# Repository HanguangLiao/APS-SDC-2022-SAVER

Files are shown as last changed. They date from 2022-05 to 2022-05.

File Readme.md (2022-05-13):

## About this Repository
The repo contains the hardware and software of the Small Antenna for Vital Emergency Response (SAVER) for APS SDC 2022. It consists of pluggable blocks for miniaturized antennas, an antenna testbench, a wristband which monitors vital signs and a mobile phone app which collects, analyzes, and plots the vital signs from the wristband.

## Folder Structure
* Antenna Testbench
    * Antenna Hardware
        - STL and STEP files of the pluggable antenna blocks
    * GUI
        - GUI of the antenna testbench run on a Raspberry Pi 4 which is also connected to PocketVNA.
* Mobile Phone App
    - MIT App Inventor Project File and the Released APK file
* Wristband
    * Hardware
        - Gerber Files, schematics, soldering guide, and bill of materials of the Wristband PCB
        * Wristband support printing
            - STL and STEP files of the wristband case
    * Software
        - PlatformIO project folder of the wristband firmware

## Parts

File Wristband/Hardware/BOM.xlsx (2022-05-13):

Name | Description | Designator | Value | Quantity
Cap | Capacitor | C1, C2 | 18pF | 2 | 31
Cap | Capacitor | C3, C9, C18, C29, C33 | 1uF | 5
Cap | Capacitor | C4, C7, C8, C10, C13, C14, C15, C19, C21, C23, C24, C25, C28, C32 | 0.1uF | 14
Cap | Capacitor | C5 | 10nF | 1
Cap | Capacitor | C6 | 3.3nF | 1
Cap | Capacitor | C11, C26, C27 | 10uF | 3
Cap | Capacitor | C16, C17 | 270pF | 2
Cap | Capacitor | C22 | 2.2nF | 1
Cap | Capacitor | C30 | 10pF | 1
Cap | Capacitor | C31 | 7pF | 1
Diode 10TQ035 | Schottky Rectifier | D1, D2 |  | 2
Antenna | Generic Antenna | E1 |  | 1
USB |  | J |  | 1
Inductor | Inductor | L1 | 1nH | 1
TS9011DCX_RFG | 250mA 1.8V Low Quiescent Current CMOS LDO | LDO1.8 |  | 1
ESP32-D0WDQ6 | IC RF TxRx + MCU Bluetooth, WiFi 802.11b/g/n, Bluetooth 4.2 2.4GHz 48-VFQFN Exposed Pad | MPU |  | 1
Header 2H | Header, 2-Pin, Right Angle | P1 |  | 1
Res3 | Resistor | R1, R10 | 20K | 2 | 19
Res3 | Resistor | R2, R11, R12 | 4.7K | 3
Res3 | Resistor | R3, R4, R7, R8 | 4.7k | 4
Res3 | Resistor | R9, R20, R21 | 0 | 3
Res3 | Resistor | R13 | 500 | 1
Res3 | Resistor | R14, R15, R16, R17, R18, R19 | 10k | 6
SW-SPST | Single-Pole, Single-Throw Switch | S1, S2 |  | 2
W25Q32JVSSIQ | FLASH - NOR Memory IC 32Mb _4M x 8_ SPI - Quad I/O 133MHz 8-SOIC | U |  | 1
MPU-6050 | Accelerometer, Gyroscope, 6 Axis Sensor IÂ²C Output | U2 |  | 1
MAX30102EFD+ | Oximeter/Heart Rate Sensor IÂ²C Output | U3 |  | 1
AMS1117-3.3 | Sot223/Pkg 1-Amp 3.3-Volt Low Drop Out Voltage Regulatator | U5 |  | 1
CH340E | USB to serial chip CH340 | U10 |  | 1
ABM8-40.000MHZ-10-1-U-T | 40MHz Â±10ppm Crystal 10pF 35 Ohms 4-SMD, No Lead | Y-40MHz |  | 1

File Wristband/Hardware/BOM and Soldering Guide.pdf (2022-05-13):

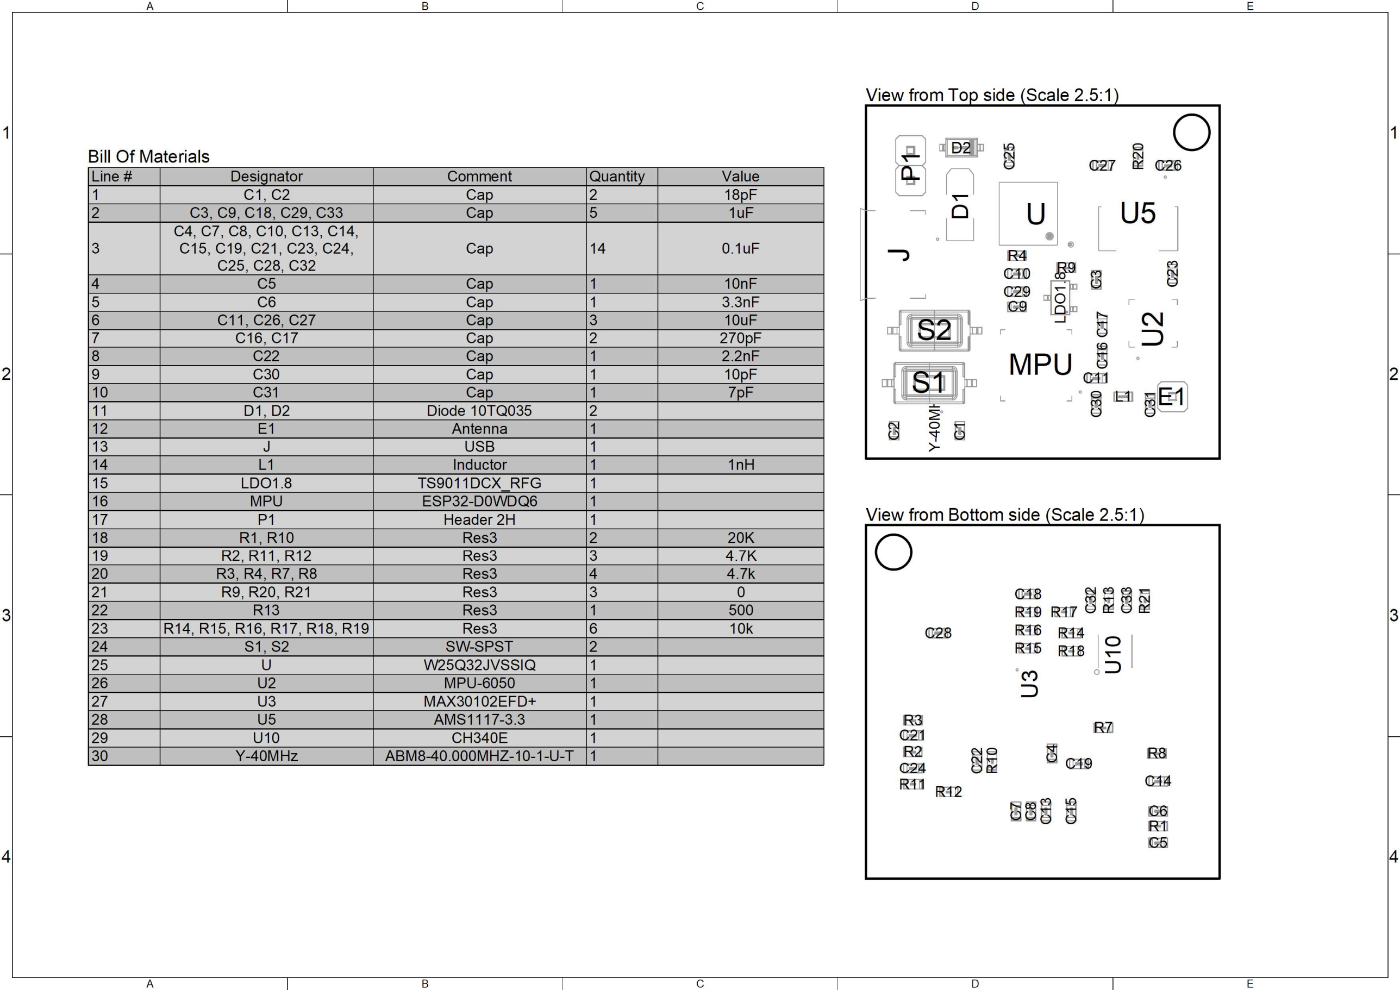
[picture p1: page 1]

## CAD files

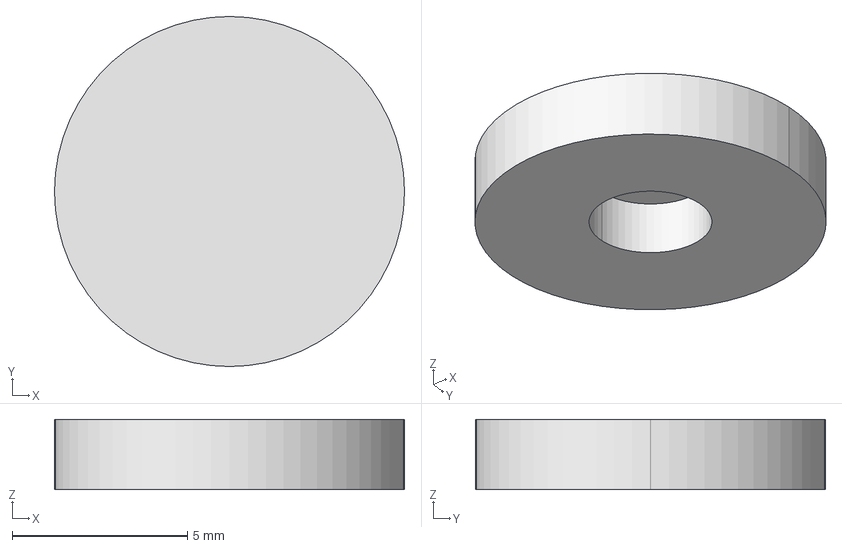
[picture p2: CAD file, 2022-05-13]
Antenna Testbench/Antenna Hardware/Antenna Models/top hat.step
10.0 x 10.0 x 2.00 mm

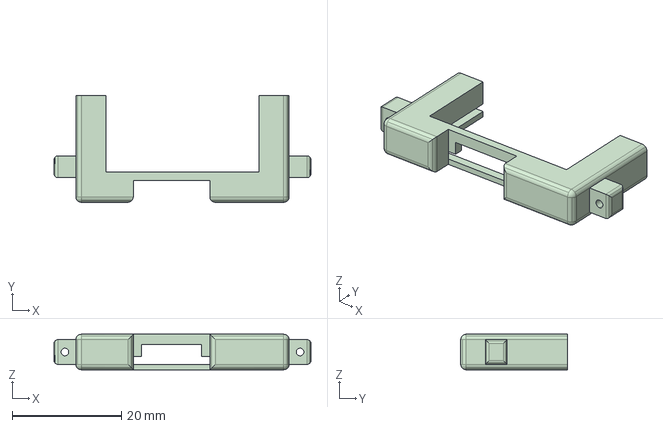
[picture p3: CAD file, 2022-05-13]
Wristband/Hardware/Wristband support printing/2nd_half.step
47.0 x 19.5 x 6.50 mm

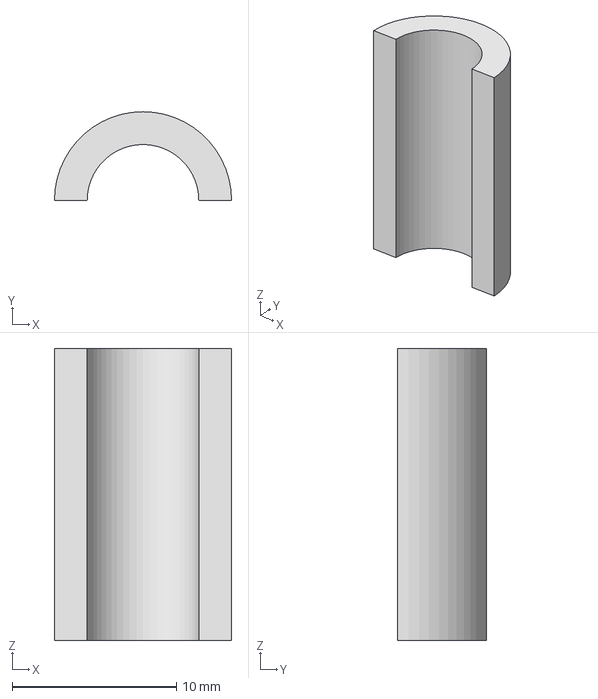
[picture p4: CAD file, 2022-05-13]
Antenna Testbench/Antenna Hardware/Antenna Models/L3.step
10.8 x 5.40 x 17.8 mm

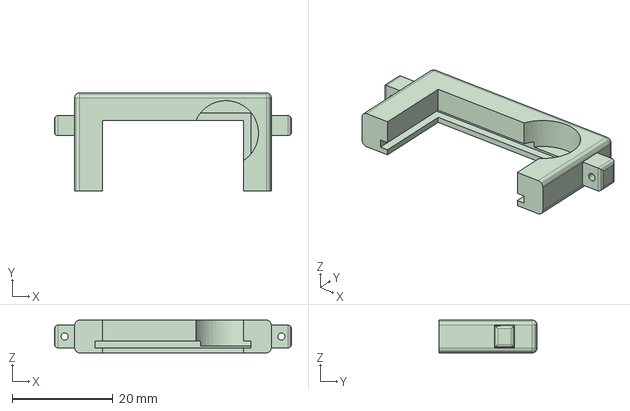
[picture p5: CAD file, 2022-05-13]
Wristband/Hardware/Wristband support printing/1st_half.step
47.0 x 19.5 x 6.50 mm

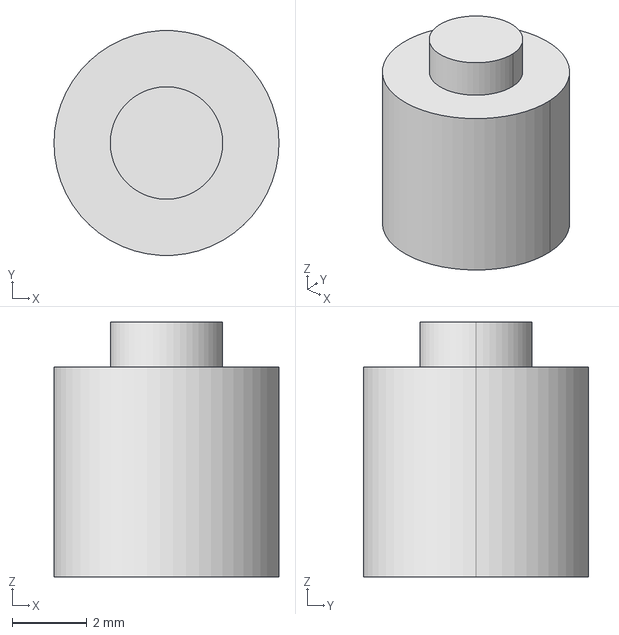
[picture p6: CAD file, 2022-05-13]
Antenna Testbench/Antenna Hardware/Antenna Models/Base.step
6.00 x 5.99 x 6.80 mm

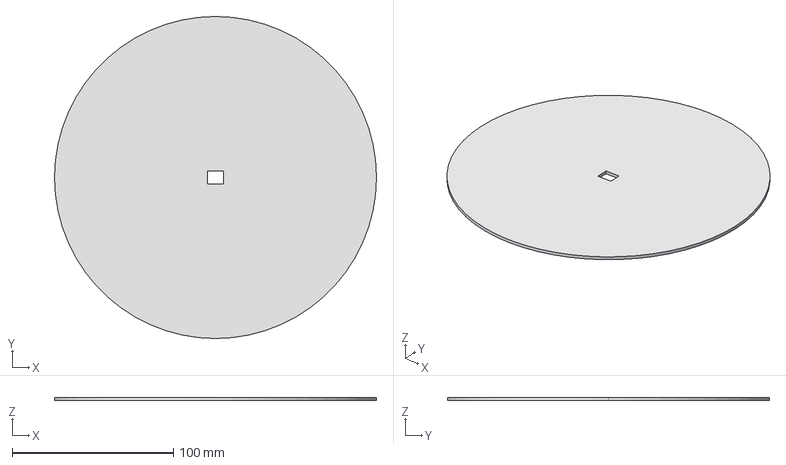
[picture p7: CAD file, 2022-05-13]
Antenna Testbench/Antenna Hardware/Antenna Models/GND_plane.step
200.0 x 200.0 x 2.00 mm

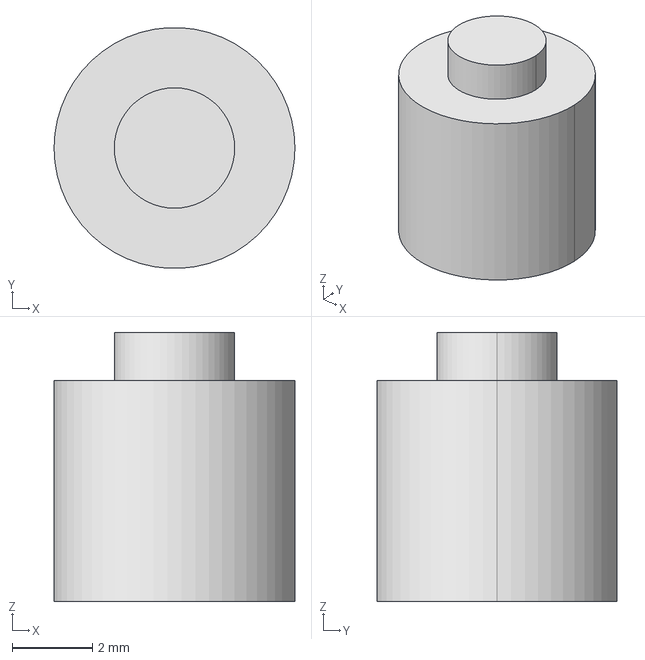
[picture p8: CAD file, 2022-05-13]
Antenna Testbench/Antenna Hardware/Antenna Models/Middle.step
6.00 x 5.99 x 6.70 mm

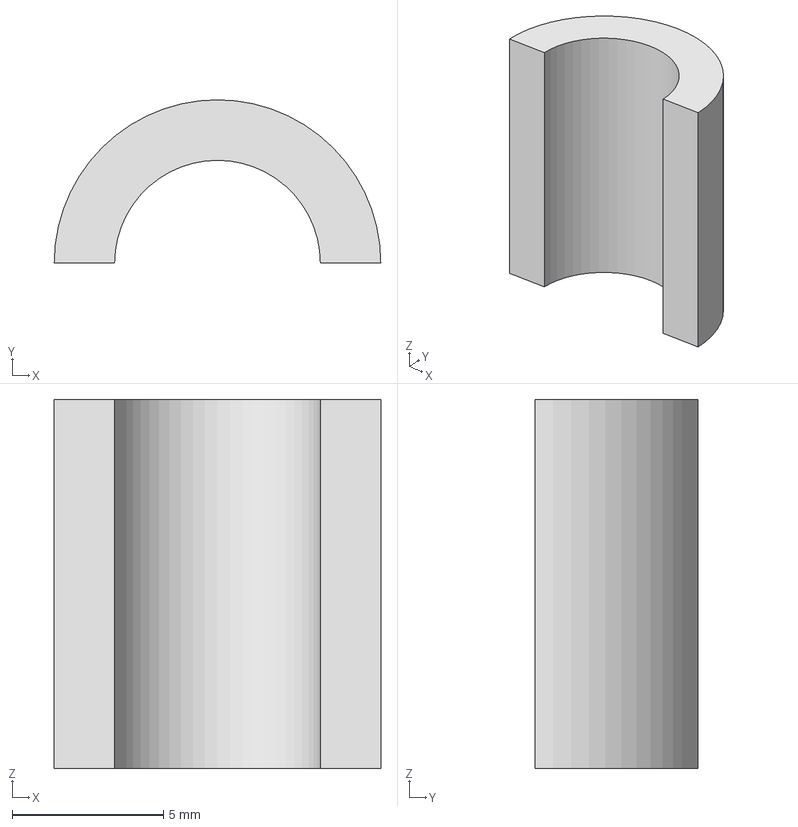
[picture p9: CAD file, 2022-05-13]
Antenna Testbench/Antenna Hardware/Antenna Models/L2.step
10.8 x 5.40 x 12.2 mm

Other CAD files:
Antenna Testbench/Antenna Hardware/Meandered linse cutting.dxf
Antenna Testbench/Antenna Hardware/Antenna Models/Base.STL
Antenna Testbench/Antenna Hardware/Antenna Models/GND_plane.STL
Antenna Testbench/Antenna Hardware/Antenna Models/L2.STL
Antenna Testbench/Antenna Hardware/Antenna Models/L3.STL
Antenna Testbench/Antenna Hardware/Antenna Models/Middle.STL
Antenna Testbench/Antenna Hardware/Antenna Models/top hat.STL
Wristband/Hardware/Wristband support printing/1st_half.STL
Wristband/Hardware/Wristband support printing/2nd_half.STL

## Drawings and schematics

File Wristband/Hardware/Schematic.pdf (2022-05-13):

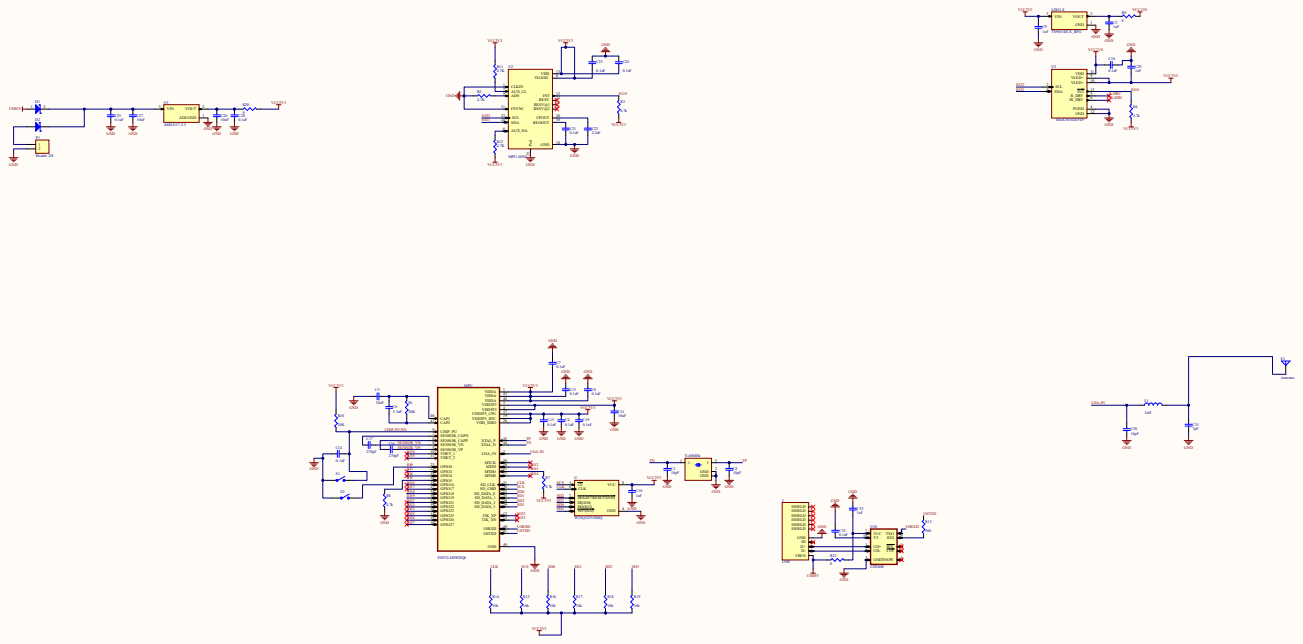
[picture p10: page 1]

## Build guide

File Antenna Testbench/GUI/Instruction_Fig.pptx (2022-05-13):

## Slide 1

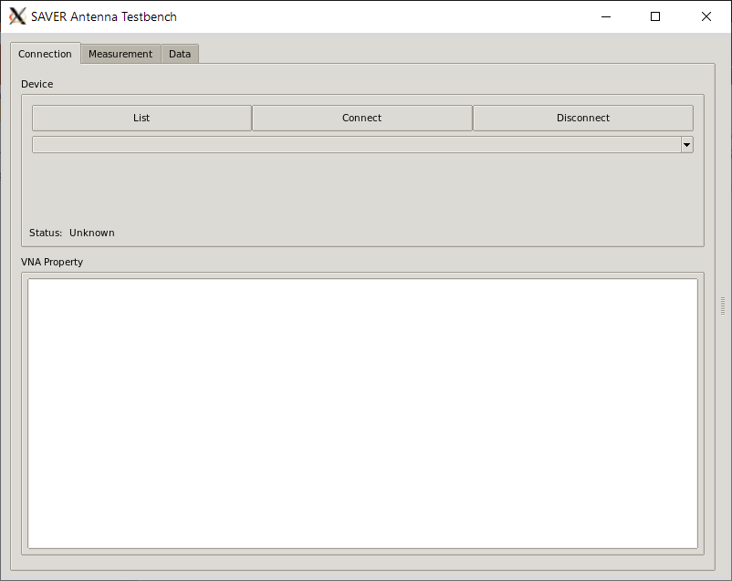
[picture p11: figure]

Step8.1

Step8.2

Step8.3

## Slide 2

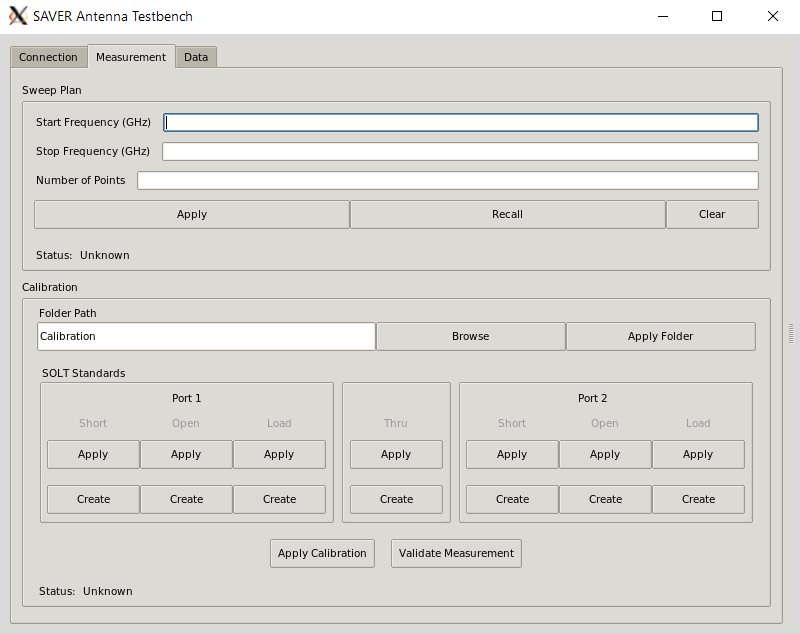
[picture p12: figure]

Step9.1

Step9.2

Step10

Step11

Step12

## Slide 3

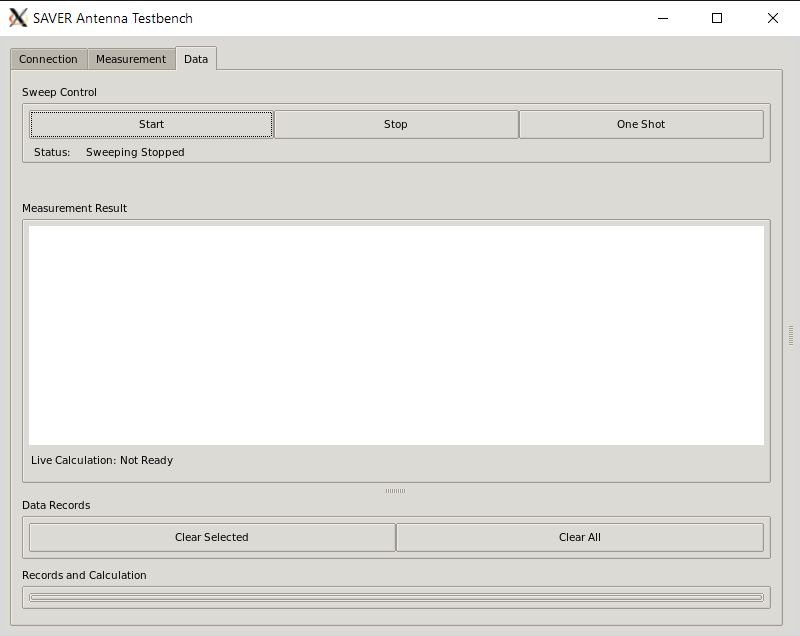
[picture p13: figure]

Step13

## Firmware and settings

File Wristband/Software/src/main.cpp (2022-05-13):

#include <Arduino.h>
#include <BLEDevice.h>
#include <BLEServer.h>
#include <BLEUtils.h>
#include <BLE2902.h>
#include <Wire.h>
#include <math.h>
#include <MAX30105.h>
#include <spo2_algorithm.h>
// Mutex and Semaphore Definitions
SemaphoreHandle_t mutex_iic;
//--------------UART--Server--Task--Begin----------------------------------
QueueHandle_t queue_serial;
const int queue_serial_buffer_size = 128;
static void task_serial_server(void * param)
{
  char receive_buffer[queue_serial_buffer_size];

  Serial.begin(115200);
  while(1)
  {
    // If receives queued request to print on serial
    if(xQueueReceive(queue_serial,receive_buffer,128) == pdTRUE)
    {
      Serial.printf("%s\n", receive_buffer);
    }
    vTaskDelay(100 / portTICK_PERIOD_MS);
  }
}
//--------------UART--Server--Task--End-----------------------------------

//--------------BLE--Server--Task--Begin-----------------------------------
QueueHandle_t queue_ble_temperature,
 queue_ble_accel, 
 queue_ble_heartbeat, 
 queue_ble_spo2;
#define SERVICE_UUID "12a59900-17cc-11ec-9621-0242ac130002"
#define CHARACTERISTIC_UUID_SPO2 "12a5a148-17cc-11ec-9621-0242ac130002"
#define CHARACTERISTIC_UUID_TEMP "a93769a2-ace1-11ec-b909-0242ac120002"
#define CHARACTERISTIC_UUID_TXHB "d084d792-ace1-11ec-b909-0242ac120002"
#define CHARACTERISTIC_UUID_TXAcce "e6097a32-ace1-11ec-b909-0242ac120002"
class BLEServerCallback : public BLEServerCallbacks
{
  public :
    int is_device_connected = 0;
    int is_device_connected_last_time = 0;
    void onConnect(BLEServer *pServer)
      {
          is_device_connected = 1;
      };

      void onDisconnect(BLEServer *pServer)
      {
          is_device_connected = 0;
      }
};
static void task_ble_server(void * param)
{
  char serial_buffer[queue_serial_buffer_size];
  sprintf(serial_buffer,"BLE: Server Created");
  xQueueSend(queue_serial, serial_buffer, 128);
  BLEServerCallback ble_server_callback;
  BLEDevice::init("ESP32_BLE");
  // setup a BLE service
  BLEServer * ble_server = BLEDevice::createServer();
  ble_server->setCallbacks(&ble_server_callback);
  BLEService * ble_service = ble_server->createService(SERVICE_UUID);

  // setup BLE characteristics
  BLECharacteristic * ble_charcteristic_spo2 = ble_service->createCharacteristic(CHARACTERISTIC_UUID_SPO2, BLECharacteristic::PROPERTY_WRITE | BLECharacteristic::PROPERTY_READ);
  BLECharacteristic * ble_charcteristic_temp = ble_service->createCharacteristic(CHARACTERISTIC_UUID_TEMP, BLECharacteristic::PROPERTY_WRITE | BLECharacteristic::PROPERTY_READ);
  BLECharacteristic * ble_charcteristic_heartbeat = ble_service->createCharacteristic(CHARACTERISTIC_UUID_TXHB, BLECharacteristic::PROPERTY_WRITE | BLECharacteristic::PROPERTY_READ);
  BLECharacteristic * ble_charcteristic_accel = ble_service->createCharacteristic(CHARACTERISTIC_UUID_TXAcce, BLECharacteristic::PROPERTY_WRITE | BLECharacteristic::PROPERTY_READ);

  // Run BLE Service
  ble_service->start();              
  ble_server->getAdvertising()->start();
  sprintf(serial_buffer,"BLE: Waiting for Connection");
  xQueueSend(queue_serial, serial_buffer, 128);
  while(1)
  {
    if(!ble_server_callback.is_device_connected && ble_server_callback.is_device_connected_last_time)
    {
      // If device is disconnecting
      ble_server->startAdvertising();
      sprintf(serial_buffer,"BLE: Disconnected and Restart Broadcasting");
      xQueueSend(queue_serial, serial_buffer, 128);
      ble_server_callback.is_device_connected_last_time = ble_server_callback.is_device_connected;
    }
    else if (ble_server_callback.is_device_connected && !ble_server_callback.is_device_connected_last_time)
    {
      // If device is connected for the first time
      ble_server_callback.is_device_connected_last_time = 1;
      sprintf(serial_buffer,"BLE: Connected");
      xQueueSend(queue_serial, serial_buffer, 128);
    }

    if(ble_server_callback.is_device_connected)
    {
      float read_buffer;
      if(xQueueReceive(queue_ble_accel, &read_buffer, 0) == pdTRUE)
        ble_charcteristic_accel->setValue(read_buffer);

      if(xQueueReceive(queue_ble_spo2, &read_buffer, 0) == pdTRUE)
        ble_charcteristic_spo2->setValue(read_buffer);

      if(xQueueReceive(queue_ble_temperature, &read_buffer, 0) == pdTRUE)
        ble_charcteristic_temp->setValue(read_buffer);

      if(xQueueReceive(queue_ble_heartbeat, &read_buffer, 0) == pdTRUE)
        ble_charcteristic_heartbeat->setValue(read_buffer);
    }
    vTaskDelay(10 / portTICK_PERIOD_MS);
  }
}
//--------------BLE--Server--Task--End-------------------------------------

//--------------MAX30102-Sensor-Read-Task--Begin--------------------------------
QueueHandle_t queue_max30102_ir, queue_max30102_red;
static void task_max30102_read(void * param)
{
  MAX30105 max30105_sensor;
  
  char serial_buffer[queue_serial_buffer_size];
  
  float temperature = 0.0f;
  int temperature_wait_tick = 0;
  
  // Check if device is connected
  while(xSemaphoreTake(mutex_iic, 100) != pdTRUE);
  if(!max30105_sensor.begin(Wire, I2C_SPEED_FAST))
  {
    sprintf(serial_buffer, "MAX30105: Sensor was not found. Please check wiring/power");
    xQueueSend(queue_serial, serial_buffer, 0);
    // Quit this task if device is not found
    xSemaphoreGive(mutex_iic);
    vTaskDelete(NULL);
  }
  xSemaphoreGive(mutex_iic);

  // Initiate device
  int sampleRate = 200; //Options: 50, 100, 200, 400, 800, 1000, 1600, 3200, Sampling Rate is also limited by LED Pulse Width （Refer to Table 11)
  byte ledBrightness = 60; //Options: 0=Off to 255=50mA
  byte sampleAverage = 4; //Options: 1, 2, 4, 8, 16, 32
  byte ledMode = 2; //Options: 1 = Red only, 2 = Red + IR, 3 = Red + IR + Green
  int pulseWidth = 411; //Options: 69, 118, 215, 411
  int adcRange = 4096; //Options: 2048, 4096, 8192, 16384
  while(xSemaphoreTake(mutex_iic, 100) != pdTRUE);
  max30105_sensor.setup(ledBrightness, sampleAverage, ledMode, sampleRate, pulseWidth, adcRange); //Configure sensor with these settings
  xSemaphoreGive(mutex_iic);

  while(1)
  {
    // Read Temperature at a speed 101 times slower than red and ir sensor
    temperature_wait_tick += 1;
    if(temperature_wait_tick > 101)
    {
      temperature_wait_tick = 0;
      while(xSemaphoreTake(mutex_iic, 0) != pdTRUE);
      temperature = max30105_sensor.readTemperature();
      //Reset SPO2 Measurement
      max30105_sensor.clearFIFO();
      xSemaphoreGive(mutex_iic);
      xQueueSend(queue_ble_temperature, &temperature, 0);
      sprintf(serial_buffer, "MAX30102: Temperature = %.2f", temperature);
      xQueueSend(queue_serial, serial_buffer, 0);
    }

    // Read IR Value
    while(xSemaphoreTake(mutex_iic, 0) != pdTRUE) vTaskDelay(1);
    uint32_t IR = max30105_sensor.getIR();
    xSemaphoreGive(mutex_iic);
    while(IR == 0)
    {
      while(xSemaphoreTake(mutex_iic, 0) != pdTRUE) vTaskDelay(1);
      IR = max30105_sensor.getIR();
      xSemaphoreGive(mutex_iic);
    }
    xQueueSend(queue_max30102_ir, &IR, 0);

    // Read Red Value
    while(xSemaphoreTake(mutex_iic, 0) != pdTRUE) vTaskDelay(1);
    uint32_t Red =  max30105_sensor.getRed();
    xSemaphoreGive(mutex_iic);
    while(Red == 0)
    {
      while(xSemaphoreTake(mutex_iic, 0) != pdTRUE) vTaskDelay(1);
      Red =  max30105_sensor.getRed();
      xSemaphoreGive(mutex_iic);
    }
    xQueueSend(queue_max30102_red, &Red, 0);

    // Sampling Rate: 25Hz (4 averaging of 200Hz / 2 Channels)
  }
}
//--------------MAX30102-Sensor-Read-Task--End--------------------------------

//--------------Heartbeat-SpO2-Algorithm-Begin--------------------------------
static void task_heartbeat_spo2_algorithm(void * param)
{
  // The bufferLength must be matched with BUFFER_SIZE in spo2_algorithm.h
  const int bufferLength = 100; //Sample Rate is 25Hz, Buffer takes 1000ms / 25 * 100 = 4 seconds to be filled
  uint32_t * irBuffer = (uint32_t * )pvPortMalloc(bufferLength * sizeof(uint32_t)); //infrared LED sensor data
  uint32_t * redBuffer = (uint32_t * )pvPortMalloc(bufferLength * sizeof(uint32_t));  //red LED sensor data
  int32_t spo2; //SPO2 value
  int8_t validSPO2; //indicator to show if the SPO2 calculation is valid
  int32_t heartRate; //heart rate value
  int8_t validHeartRate; //indicator to show if the heart rate calculation is valid

  char serial_buffer[queue_serial_buffer_size];

  float spo2_stored = 100.0f;
  float spo2_float = 0.0f;
  const float spo2_limit = 10.0f;
  float heartRate_stored = 80.0f;
  float heartRate_float = 0.0f;
  const float heartRate_limit = 10.0f;

  if(irBuffer == NULL || redBuffer == NULL)
  {
    sprintf(serial_buffer, "Algorithm: Error, Cannot Create Heap for Sensor Data");
    xQueueSend(queue_serial, serial_buffer, 0);
    vTaskDelete(NULL);
  }

  //Continuously taking samples from MAX30102.  Heart rate and SpO2 are calculated every 2 second
  while(1)
  {
    TickType_t start_tick = xTaskGetTickCount();
    // Reading takes 1000ms / 25 * 100 = 4 seconds
    for (int i = 0; i < bufferLength; i++)
    {
      while(xQueueReceive(queue_max30102_ir, &irBuffer[i], 0) != pdTRUE) vTaskDelay(1 / portTICK_PERIOD_MS);
      while(xQueueReceive(queue_max30102_red, &redBuffer[i], 0) != pdTRUE) vTaskDelay(1 / portTICK_PERIOD_MS);
    }
    TickType_t count_tick = xTaskGetTickCount() - start_tick;
    sprintf(serial_buffer, "Algorithm: reading takes %d ticks", count_tick);
    xQueueSend(queue_serial, serial_buffer, 0);

    // Calculate Heart Rate and SpO2 Every 4 seconds
    maxim_heart_rate_and_oxygen_saturation(irBuffer, bufferLength, redBuffer, &spo2, &validSPO2, &heartRate, &validHeartRate);

    // Software Filtering (Maximum Slew Rate) to Reduce the Effect of Abrupt Change in Calculated HeartRate
    spo2_float = (float)spo2 * (float)validSPO2;
    if(spo2_float > spo2_stored + spo2_limit)
    {
      spo2_stored += spo2_limit;
    }
    else if(spo2_float < spo2_stored - spo2_limit)
    {
      spo2_stored -= spo2_limit;
    }
    else
    {
      spo2_stored = spo2_float;
    }
    
    heartRate_float = (float)heartRate * (float)validHeartRate;
    if(heartRate_float > heartRate_stored + heartRate_limit)
    {
      heartRate_stored += heartRate_limit;
    }
    else if(heartRate_float < heartRate_stored - heartRate_limit)
    {
      heartRate_stored -= heartRate_limit;
    }
    else
    {
      heartRate_stored = heartRate_float;
    }

    //Update Value to BLE and Serial Monitor
    float ble_heart_rate_buffer, ble_spo2_buffer;
    ble_heart_rate_buffer = heartRate_stored;
    xQueueSend(queue_ble_heartbeat, &ble_heart_rate_buffer, 0);
    ble_spo2_buffer = spo2_stored;
    xQueueSend(queue_ble_spo2, &ble_spo2_buffer, 0);

    sprintf(serial_buffer, "Algorithm: SpO2 = %.2f, HeartRate = %.2f", ble_spo2_buffer, ble_heart_rate_buffer);
    xQueueSend(queue_serial, serial_buffer, 0);

    vTaskDelay(10 / portTICK_PERIOD_MS);
  }
  vPortFree(irBuffer);
  vPortFree(redBuffer);
}
//--------------Heartbeat-SpO2-Algorithm-End----------------------------------

//--------------MPU-Sensor-Read-Task--Begin--------------------------------
static void task_mpu_read(void * param)
{
  char serial_buffer[queue_serial_buffer_size];

  const u_char MPU6050_Addr = 0x68;
  const u_char ACCEL_CONFIG = 0x1C;
  const u_char PWR_MGMT_1 = 0x6B;
  const u_char ACCEL_XOUT = 0x3B;
  u_char XH,XL,YH,YL,ZH,ZL;
  int16_t ACCEL_X, ACCEL_Y, ACCEL_Z;

  // Turn on the MPU6050 Sensor
  while(xSemaphoreTake(mutex_iic, 10) != pdTRUE);
  Wire.begin();
	Wire.beginTransmission(MPU6050_Addr);
  Wire.write(PWR_MGMT_1);
  Wire.write(0x00);
  Wire.endTransmission(true);
  xSemaphoreGive(mutex_iic);

  // Set MPU6050 Accel Range
  while(xSemaphoreTake(mutex_iic, 10) != pdTRUE);
  Wire.beginTransmission(MPU6050_Addr);
  // AFS_SEL = 0b11, accel scale = 16g, Sensitivity = 2048LSB per g
  Wire.write(ACCEL_CONFIG);
  Wire.write((uint8_t)(0x00 | 0x03<<3));
  Wire.endTransmission(true);
  xSemaphoreGive(mutex_iic);

  sprintf(serial_buffer,"MPU6050: Sensor Initialized");
  xQueueSend(queue_serial, serial_buffer, 128);

  while(1)
  {
    while(xSemaphoreTake(mutex_iic, 10) != pdTRUE) vTaskDelay(pdMS_TO_TICKS(1));
    Wire.beginTransmission(MPU6050_Addr);
    Wire.write(ACCEL_XOUT);
    Wire.endTransmission(false);
    Wire.requestFrom((uint16_t)MPU6050_Addr, (uint8_t)6, (bool)true);
    // Reads the data from the register
    XH = Wire.read(); 
    XL = Wire.read(); 
    YH = Wire.read();  
    YL = Wire.read();
    ZH = Wire.read();
    ZL = Wire.read();
    xSemaphoreGive(mutex_iic);

    ACCEL_X = (((int16_t)XH) << 8) | (int16_t)XL;
    ACCEL_Y = (((int16_t)YH) << 8) | (int16_t)YL;
    ACCEL_Z = (((int16_t)ZH) << 8) | (int16_t)ZL;

    float accel_x = (float)ACCEL_X / 2048.0f;
    float accel_y = (float)ACCEL_Y / 2048.0f;
    float accel_z = (float)ACCEL_Z / 2048.0f;

    float accel = sqrtf(accel_x * accel_x + accel_y * accel_y + accel_z * accel_z);
    xQueueSend(queue_ble_accel, &accel, 0);

    // sprintf(serial_buffer,"MPU6050: AccelX = %.2f\tAccelY = %.2f\tAccelZ = %.2f", accel_x, accel_y, accel_z);
    // xQueueSend(queue_serial, serial_buffer, 0);

    vTaskDelay(100 / portTICK_PERIOD_MS);
  }
}

//--------------MPU-Sensor-Read-Task--End----------------------------------
void setup()
{
  queue_serial = xQueueCreate(32, queue_serial_buffer_size * sizeof(char));
  xTaskCreate(task_serial_server, "Serial Server", 4096, NULL, 1, NULL);
  
  queue_ble_temperature = xQueueCreate(32, sizeof(float));
  queue_ble_accel = xQueueCreate(32, sizeof(float));
  queue_ble_heartbeat = xQueueCreate(32, sizeof(float));
  queue_ble_spo2 = xQueueCreate(32, sizeof(float));
  xTaskCreatePinnedToCore(task_ble_server, "BLE Server", 4096, NULL, 4, NULL, 0);

  mutex_iic = xSemaphoreCreateMutex();
  xTaskCreate(task_mpu_read, "MPU6050 Reader", 4096, NULL, 3, NULL);

  queue_max30102_ir = xQueueCreate(1024, sizeof(uint32_t));
  queue_max30102_red = xQueueCreate(1024, sizeof(uint32_t));
  xTaskCreate(task_max30102_read, "MAX30102 Reader", 4096, NULL, 3, NULL);

  xTaskCreate(task_heartbeat_spo2_algorithm, "Algorithm", 40960, NULL, 2, NULL);
}

void loop()
{
  vTaskDelete(NULL);
}
